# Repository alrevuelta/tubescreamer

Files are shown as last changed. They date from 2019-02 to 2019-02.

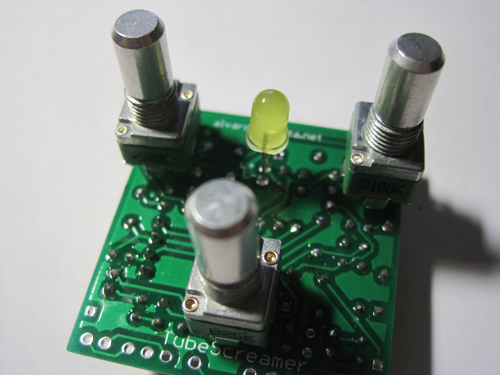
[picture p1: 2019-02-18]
img/img5.png

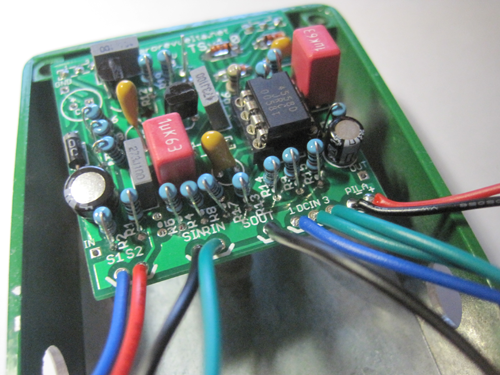
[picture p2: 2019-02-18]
img/img4.png

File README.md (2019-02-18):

# Description

This repository contains the schematics of a Tubescreamer like guitar pedal in EagleCad. This guitar pedal is a classical overdrive very well known among guitar players, specially in blues and rock style. It has several editions and modifications, such as TS-808, TS9 or TS10.

This schematics are based on the TS-808 edition, and the schematics found at gaussmarkov.net website.

<p align="center">
  
</p>

# Features

Note that the hardware available at the `hw` folder, has been designed and routed trying to avoid complex wiring. For example, the potentiometers are soldered directly to the PCB, so no wiring is needed for them. Also, the LED can be soldered to the PCB directly without extra wiring. All other connections, such as 3DPDT and in/out TRS jacks, are disposed in an order that tries to avoid wires crossing, making it cleaner that in other designs.

The pedal can be used with a 9v battery or connected to a DC source at the same voltage. Note that the typical low pass filter is included.

<p align="center">
  
</p>

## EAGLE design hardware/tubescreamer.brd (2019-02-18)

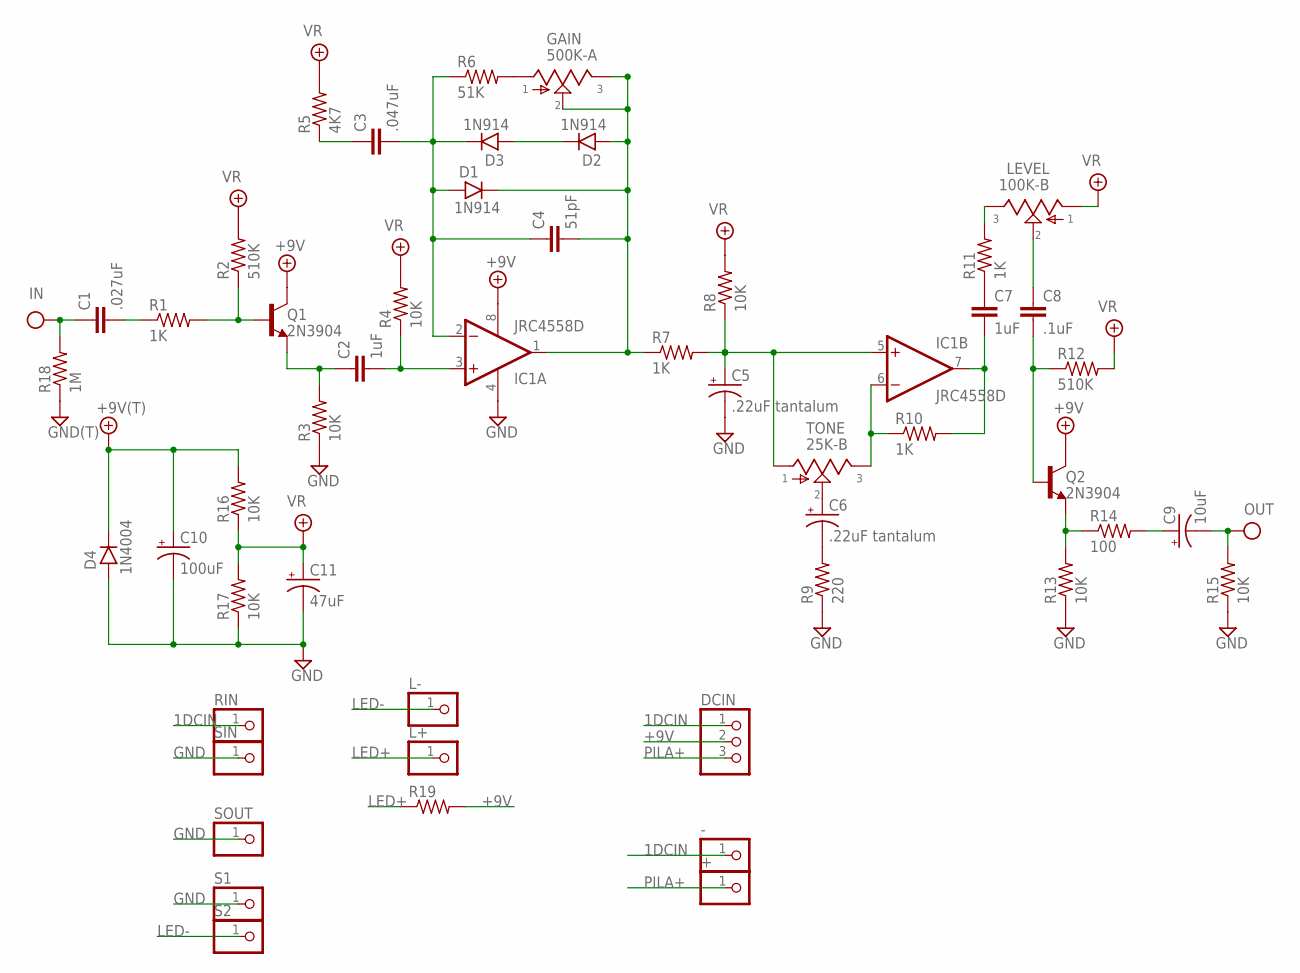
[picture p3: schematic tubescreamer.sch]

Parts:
+: PINHD-1X1CB; 1X01-CLEANBIG
+9V: +9V(T); PAD
-: PINHD-1X1CB; 1X01-CLEANBIG
C1: .027uF; 072X025
C2, C7: 1uF; 072X035
C3: .047uF; 072X025
C4: 51pF; 050X030_025_2
C5: .22uF tantalum; 044A_2
C6: .22uF tantalum; 044A
C8: .1uF; 072X025
C9: 10uF; 050_020_1
C10: 100uF; 063_025
C11: 47uF; 050_020_1
D1, D2, D3: 1N914; DO35-2
D4: 1N4004; DO41-3
DCIN: PINHD-1X3CB; 1X03-CLEANBIG
GAIN: 500K-A; POT
GND: GND(T); PAD
IC1: JRC4558D; DIL08
IN: IN(T); PAD
L+: PINHD-1X1CB; 1X01-CLEANBIG
L-: PINHD-1X1CB; 1X01-CLEANBIG
LEVEL: 100K-B; POT
OUT: OUT(T); PAD
Q1, Q2: 2N3904; TO92-
R1, R7, R10, R11: 1K; R0207/1V
R2, R12: 510K; R0207/1V
R3, R4, R8, R13, R15, R16, R17: 10K; R0207/1V
R5: 4K7; R0207/1V
R6: 51K; R0207/1V
R9: 220; R0207/1V
R14: 100; R0207/1V
R18: 1M; R0207/1V
R19: 6MM.1; R0207/1V
RIN: PINHD-1X1CB; 1X01-CLEANBIG
S1, S2: PINHD-1X1CB; 1X01-CLEANBIG
SIN: PINHD-1X1CB; 1X01-CLEANBIG
SOUT: PINHD-1X1CB; 1X01-CLEANBIG
TONE: 25K-B; POT

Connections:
1DCIN: -.1, DCIN.1, RIN.1
+9V: +9V.1, C10.+, D4.C, DCIN.2, IC1.8 (V+), Q1.1 (C), Q2.1 (C), R16.2, R19.2
GND: C5.2 (-), C10.-, C11.-, D4.A, GND.1, IC1.4 (V-), R3.1, R9.1, R13.1, R15.1, R17.1, R18.1, S1.1, SIN.1, SOUT.1
IN: C1.1, IN.1, R18.2
LED+: L+.1, R19.1
LED-: L-.1, S2.1
unnamed: GAIN.1, R6.2
unnamed: C1.2, R1.1
unnamed: Q1.2 (B), R1.2, R2.1
unnamed: C2.2, IC1.3 (+IN), R4.1
unnamed: C3.2, C4.1, D1.A, D3.C, IC1.2 (-IN), R6.1
unnamed: C2.1, Q1.3 (E), R3.2
unnamed: C4.2, D1.C, D2.A, GAIN.2, GAIN.3, IC1.1 (OUT), R7.1
unnamed: C6.1 (+), TONE.2
unnamed: C5.1 (+), IC1.5 (+IN), R7.2, R8.1, TONE.1
unnamed: IC1.6 (-IN), R10.1, TONE.3
unnamed: C3.1, R5.1
unnamed: C6.2 (-), R9.2
unnamed: C7.1, R11.1
unnamed: C7.2, IC1.7 (OUT), R10.2
unnamed: LEVEL.3, R11.2
unnamed: Q2.3 (E), R13.2, R14.1
unnamed: C8.1, LEVEL.2
unnamed: C8.2, Q2.2 (B), R12.1
unnamed: C9.+, R14.2
unnamed: D2.C, D3.A
OUT: C9.-, OUT.1, R15.2
PILA+: +.1, DCIN.3
VR: C11.+, LEVEL.1, R2.2, R4.2, R5.2, R8.2, R12.2, R16.1, R17.2

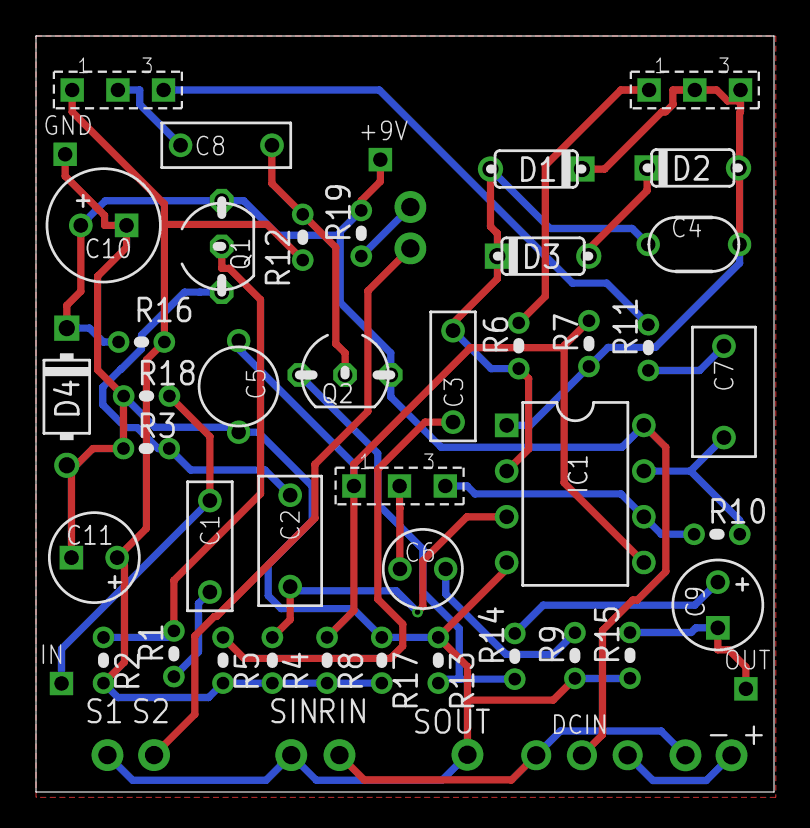
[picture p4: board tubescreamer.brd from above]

Board: 2 copper layers, 41.0 x 42.0 mm, 54 parts (0 on the bottom side), 29 nets.

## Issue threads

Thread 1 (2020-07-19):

How do you connect the 3dpdt

ardaa, 2020-07-19:
question in the title

alrevuelta, 2020-07-20:
It should be clear from the `.sch` file. There are 9 pins:
* Input jack
* Output jack
* Input to circuit
* Output form circuit
* Two pins are bridged
* Ground
* Vcc

See [this](https://github.com/alrevuelta/tubescreamer/blob/master/img/img10.png)

Closed 2020-07-20.
